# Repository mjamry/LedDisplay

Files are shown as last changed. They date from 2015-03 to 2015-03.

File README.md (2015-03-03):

# LedDisplay
This is a simple project which aim was to create LED display.<br>
Whole display is made using three 8x8 LED matrixes which are driven by ATMEL ATiny2313 microcontroller.<br><br>

Main aim was to put whole display into small case (Z76) which dimensions are 60x110mm.

For more detailed description, schematics and PCBs take a look at wiki pages.

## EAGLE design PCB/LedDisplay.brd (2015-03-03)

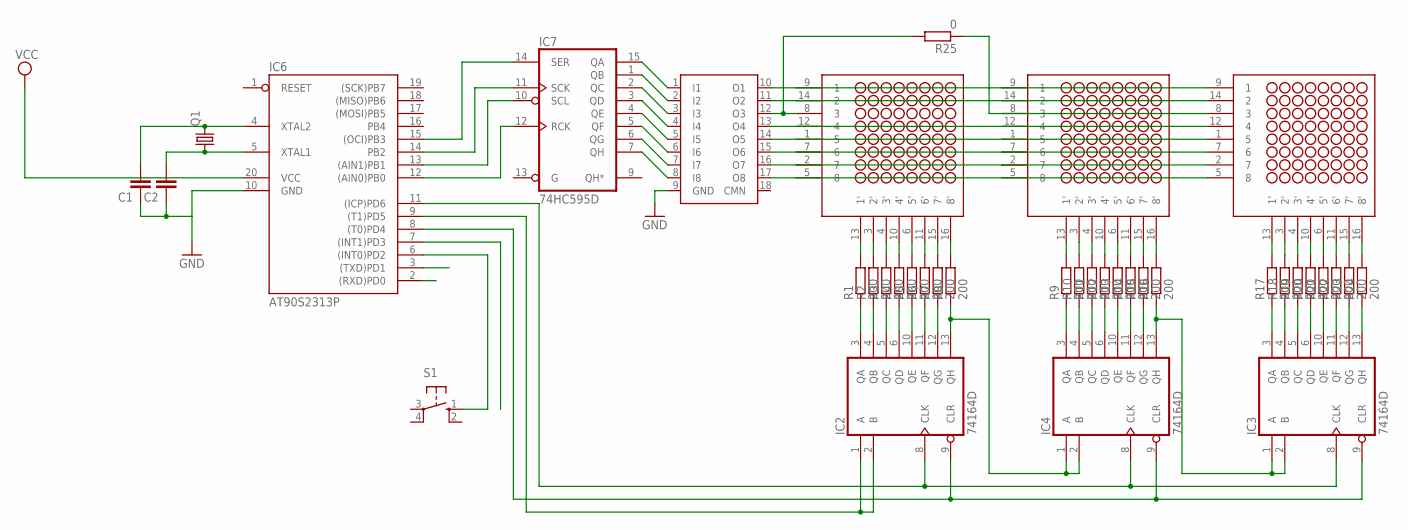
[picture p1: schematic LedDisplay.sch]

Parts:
C1, C2: C2,5-3; C2.5-3
IC2, IC3, IC4: 74164D; SO14
IC6: AT90S2313P; DIL20
IC7: 74HC595D; SO16
Q1: CRYSTALHC49U70; HC49U70
R1, R2, R3, R4, R5, R6, R7, R8, R9, R10, R11, R12, R13, R14, R15, R16, R17, R18, R19, R20, R21, R22, R23, R24: 200; M1206
R25: 0; M1206
S1: 10-XX; B3F-10XX
U$1, U$2, U$3: NFM-12881BG-11
U$4: ULN2803A; SO18W

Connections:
GND: C1.1, C2.1, IC2.7 (GND), IC3.7 (GND), IC4.7 (GND), IC6.10 (GND), IC7.8 (GND), U$4.9 (GND)
unnamed: IC7.7 (QH), U$4.8 (I8)
unnamed: IC7.6 (QG), U$4.7 (I7)
unnamed: IC7.5 (QF), U$4.6 (I6)
unnamed: IC7.4 (QE), U$4.5 (I5)
unnamed: IC7.3 (QD), U$4.4 (I4)
unnamed: IC7.2 (QC), U$4.3 (I3)
unnamed: IC7.1 (QB), U$4.2 (I2)
unnamed: IC7.15 (QA), U$4.1 (I1)
unnamed: R1.2, U$1.13 (1')
unnamed: R2.2, U$1.3 (2')
unnamed: R3.2, U$1.4 (3')
unnamed: R4.2, U$1.10 (4')
unnamed: R5.2, U$1.6 (5')
unnamed: R6.2, U$1.11 (6')
unnamed: R7.2, U$1.15 (7')
unnamed: R8.2, U$1.16 (8')
unnamed: IC2.3 (QA), R1.1
unnamed: IC2.4 (QB), R2.1
unnamed: IC2.5 (QC), R3.1
unnamed: IC2.6 (QD), R4.1
unnamed: IC2.10 (QE), R5.1
unnamed: IC2.11 (QF), R6.1
unnamed: IC2.12 (QG), R7.1
unnamed: IC2.13 (QH), IC4.1 (A), IC4.2 (B), R8.1
unnamed: R9.2, U$2.13 (1')
unnamed: R10.2, U$2.3 (2')
unnamed: R11.2, U$2.4 (3')
unnamed: R12.2, U$2.10 (4')
unnamed: R13.2, U$2.6 (5')
unnamed: R14.2, U$2.11 (6')
unnamed: R15.2, U$2.15 (7')
unnamed: R16.2, U$2.16 (8')
unnamed: IC4.3 (QA), R9.1
unnamed: IC4.4 (QB), R10.1
unnamed: IC4.5 (QC), R11.1
unnamed: IC4.6 (QD), R12.1
unnamed: IC4.10 (QE), R13.1
unnamed: IC4.11 (QF), R14.1
unnamed: IC4.12 (QG), R15.1
unnamed: IC3.1 (A), IC3.2 (B), IC4.13 (QH), R16.1
unnamed: R17.2, U$3.13 (1')
unnamed: R18.2, U$3.3 (2')
unnamed: R19.2, U$3.4 (3')
unnamed: R20.2, U$3.10 (4')
unnamed: R21.2, U$3.6 (5')
unnamed: R22.2, U$3.11 (6')
unnamed: R23.2, U$3.15 (7')
unnamed: R24.2, U$3.16 (8')
unnamed: IC3.3 (QA), R17.1
unnamed: IC3.4 (QB), R18.1
unnamed: IC3.5 (QC), R19.1
unnamed: IC3.6 (QD), R20.1
unnamed: IC3.10 (QE), R21.1
unnamed: IC3.11 (QF), R22.1
unnamed: IC3.12 (QG), R23.1
unnamed: IC3.13 (QH), R24.1
unnamed: C1.2, IC6.4 (XTAL2), Q1.2
unnamed: C2.2, IC6.5 (XTAL1), Q1.1
unnamed: IC2.9 (CLR), IC3.9 (CLR), IC4.9 (CLR), IC6.8 ((T0)PD4)
unnamed: IC2.1 (A), IC2.2 (B), IC6.9 ((T1)PD5)
unnamed: IC2.8 (CLK), IC3.8 (CLK), IC4.8 (CLK), IC6.11 ((ICP)PD6)
unnamed: IC6.6 ((INT0)PD2), S1.1 (S)
unnamed: U$1.9 (1), U$2.9 (1), U$3.9 (1), U$4.10 (O1)
unnamed: U$1.14 (2), U$2.14 (2), U$3.14 (2), U$4.11 (O2)
unnamed: R25.1, U$2.8 (3), U$3.8 (3)
unnamed: U$1.12 (4), U$2.12 (4), U$3.12 (4), U$4.13 (O4)
unnamed: U$1.1 (5), U$2.1 (5), U$3.1 (5), U$4.14 (O5)
unnamed: U$1.7 (6), U$2.7 (6), U$3.7 (6), U$4.15 (O6)
unnamed: U$1.2 (7), U$2.2 (7), U$3.2 (7), U$4.16 (O7)
unnamed: U$1.5 (8), U$2.5 (8), U$3.5 (8), U$4.17 (O8)
unnamed: IC6.12 ((AIN0)PB0), IC7.12 (RCK)
unnamed: IC6.13 ((AIN1)PB1), IC7.10 (SCL)
unnamed: IC6.14 (PB2), IC7.11 (SCK)
unnamed: IC6.15 ((OCI)PB3), IC7.14 (SER)
unnamed: R25.2, U$1.8 (3), U$4.12 (O3)
VCC: IC2.14 (VCC), IC3.14 (VCC), IC4.14 (VCC), IC6.20 (VCC), IC7.16 (VCC)

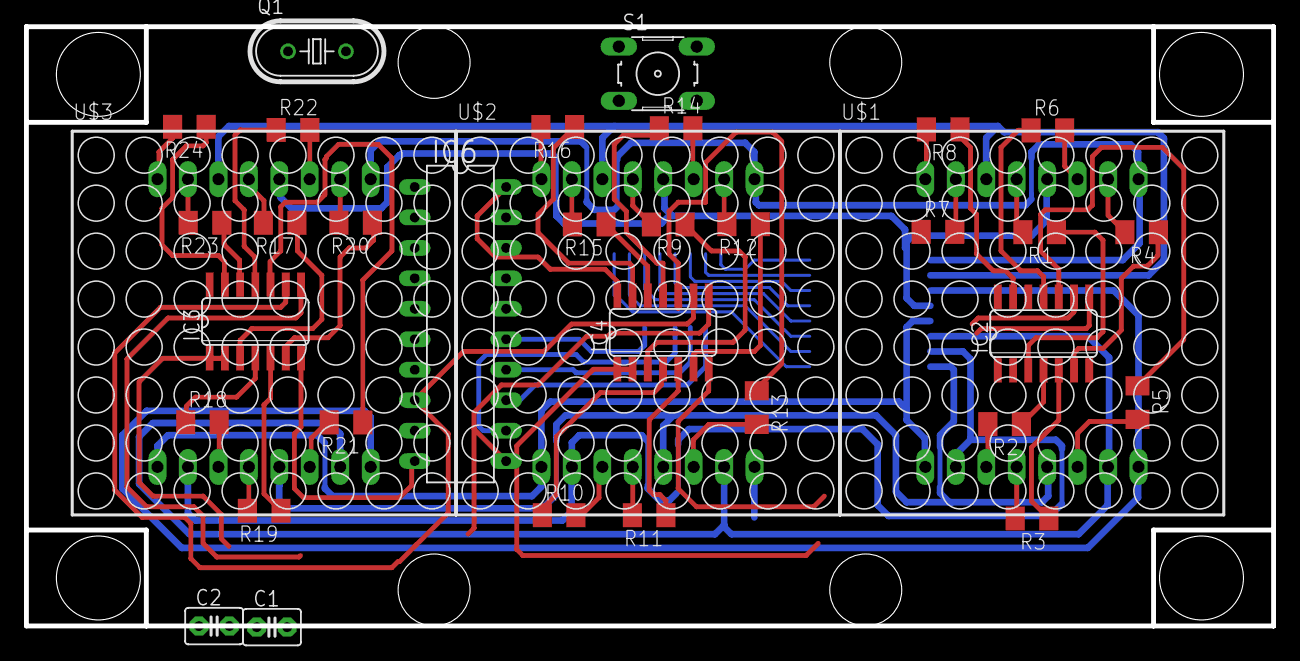
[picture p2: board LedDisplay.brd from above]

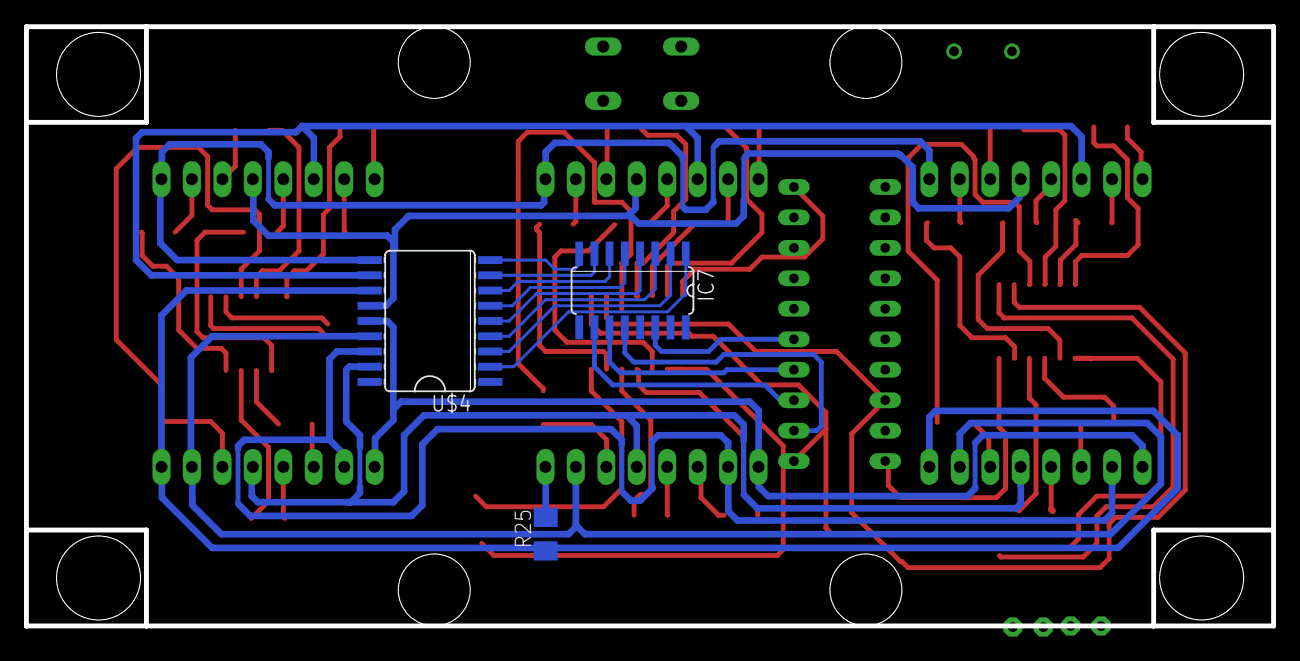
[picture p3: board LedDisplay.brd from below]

Board: 2 copper layers, 104.0 x 50.0 mm, 38 parts (3 on the bottom side), 77 nets.

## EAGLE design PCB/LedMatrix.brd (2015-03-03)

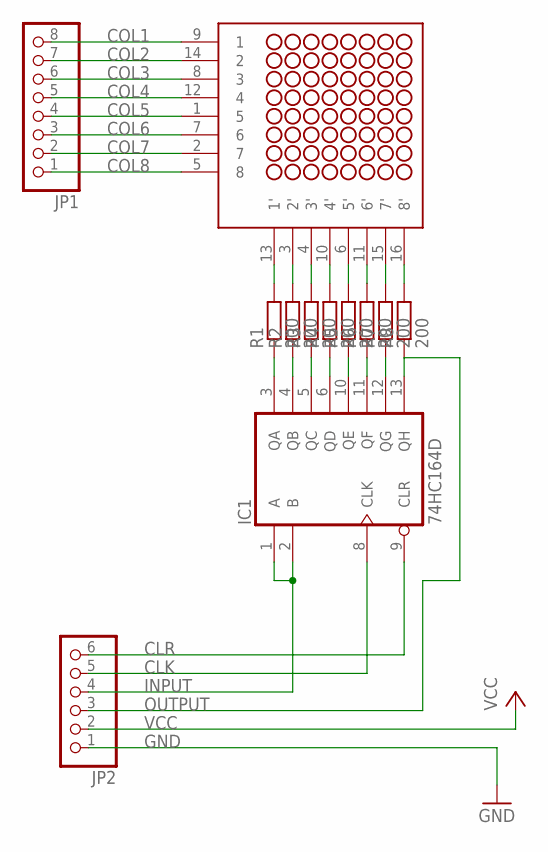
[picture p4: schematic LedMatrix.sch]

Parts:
IC1: 74HC164D; SO14
JP1: PINHD-1X8; 1X08
JP2: PINHD-1X6; 1X06
R1, R2, R3, R4, R5, R6, R7, R8: 200; R1206
U$1: NFM-12881BG-11

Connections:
CLK: IC1.8 (CLK), JP2.5
CLR: IC1.9 (CLR), JP2.6
COL1: JP1.8, U$1.9 (1)
COL2: JP1.7, U$1.14 (2)
COL3: JP1.6, U$1.8 (3)
COL4: JP1.5, U$1.12 (4)
COL5: JP1.4, U$1.1 (5)
COL6: JP1.3, U$1.7 (6)
COL7: JP1.2, U$1.2 (7)
COL8: JP1.1, U$1.5 (8)
GND: IC1.7 (GND), JP2.1
INPUT: IC1.1 (A), IC1.2 (B), JP2.4
unnamed: R1.2, U$1.13 (1')
unnamed: R2.2, U$1.3 (2')
unnamed: R3.2, U$1.4 (3')
unnamed: R4.2, U$1.10 (4')
unnamed: R5.2, U$1.6 (5')
unnamed: R6.2, U$1.11 (6')
unnamed: R7.2, U$1.15 (7')
unnamed: R8.2, U$1.16 (8')
unnamed: IC1.3 (QA), R1.1
unnamed: IC1.4 (QB), R2.1
unnamed: IC1.5 (QC), R3.1
unnamed: IC1.6 (QD), R4.1
unnamed: IC1.10 (QE), R5.1
unnamed: IC1.11 (QF), R6.1
unnamed: IC1.12 (QG), R7.1
OUTPUT: IC1.13 (QH), JP2.3, R8.1
VCC: IC1.14 (VCC), JP2.2

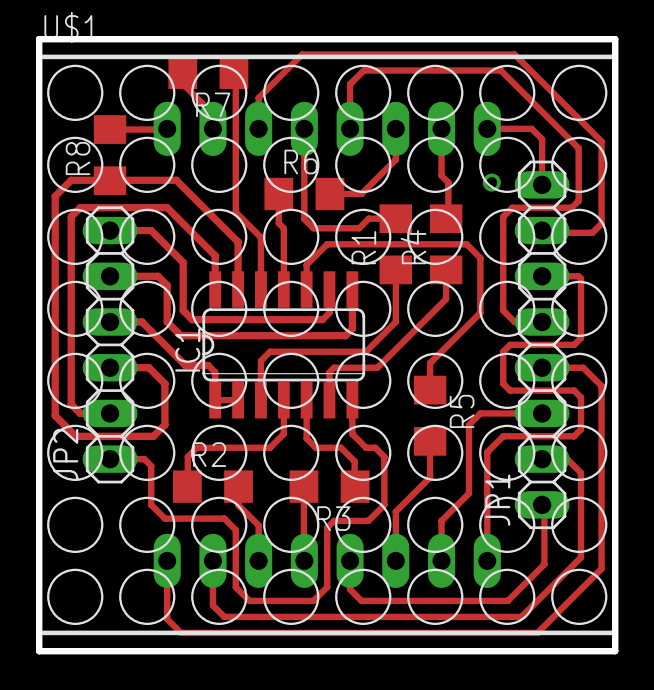
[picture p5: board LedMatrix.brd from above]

Board: 2 copper layers, 32.0 x 34.0 mm, 12 parts (0 on the bottom side), 29 nets.

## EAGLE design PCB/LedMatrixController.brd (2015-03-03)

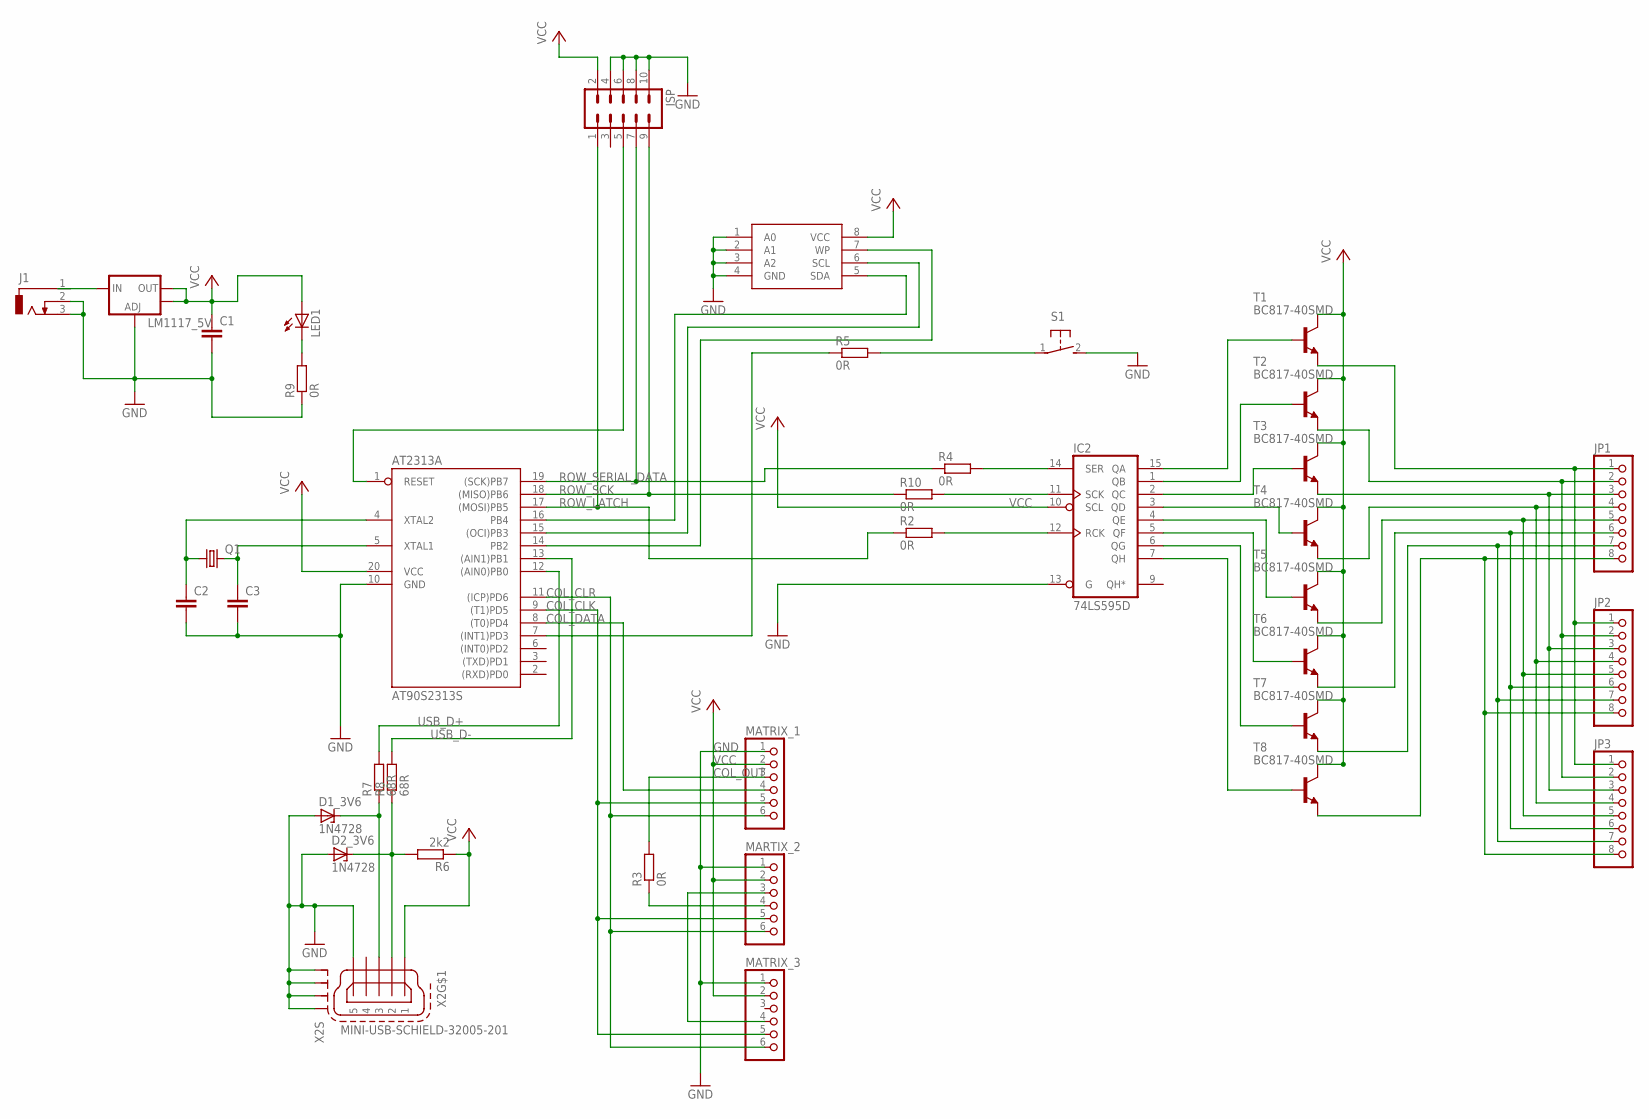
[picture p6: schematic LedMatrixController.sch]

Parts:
AT2313A: AT90S2313S; SO20L
C1: C-EU025-025X050; C025-025X050
C2, C3: C-EUC1206; C1206
D1_3V6, D2_3V6: 1N4728; DO41Z10
EEPROM: AT24C08; SO08
IC2: 74LS595D; SO16
ISP: ML10
J1: DCJ0303
JP1, JP2, JP3: PINHD-1X8; 1X08
LED1: LEDCHIPLED_1206; CHIPLED_1206
LM1117_5V: V_REG_LM1117SOT223; SOT223
MARTIX_2: PINHD-1X6; 1X06
MATRIX_1, MATRIX_3: PINHD-1X6; 1X06
Q1: CRYSTALHC49UP; HC49UP
R2, R3, R4, R5, R9, R10: 0R; R1206
R6: 2k2; R1206
R7, R8: 68R; R1206
S1: 31-XX; B3F-31XX
T1, T2, T3, T4, T5, T6, T7, T8: BC817-40SMD; SOT23-BEC
X2: MINI-USB-SCHIELD-32005-201; 32005-201

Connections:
+5V: IC2.16 (VCC)
COL_CLK: AT2313A.9 ((T1)PD5), MARTIX_2.5, MATRIX_1.5, MATRIX_3.5
COL_CLR: AT2313A.11 ((ICP)PD6), MARTIX_2.6, MATRIX_1.6, MATRIX_3.6
COL_DATA: AT2313A.8 ((T0)PD4), MATRIX_1.4
COL_OUT: MATRIX_1.3, R3.2
COL_OUT_2: MARTIX_2.4, R3.1
GND: AT2313A.10 (GND), C1.2, C2.2, C3.2, D1_3V6.A, D2_3V6.A, EEPROM.1 (A0), EEPROM.2 (A1), EEPROM.3 (A2), EEPROM.4 (GND), IC2.8 (GND), IC2.13 (G), ISP.4, ISP.6, ISP.8, ISP.10, J1.2, J1.3, LM1117_5V.1 (ADJ), MARTIX_2.1, MATRIX_1.1, MATRIX_3.1, R9.1, S1.2 (S), X2.5, X2.M1 (S1), X2.M2 (S2), X2.M3 (S3), X2.M4 (S4)
unnamed: AT2313A.4 (XTAL2), C2.1, Q1.1
unnamed: J1.1, LM1117_5V.3 (IN)
unnamed: AT2313A.5 (XTAL1), C3.1, Q1.2
unnamed: AT2313A.7 ((INT1)PD3), R5.1
unnamed: IC2.12 (RCK), R2.2
unnamed: AT2313A.16 (PB4), EEPROM.5 (SDA)
unnamed: IC2.14 (SER), R4.2
unnamed: MARTIX_2.3, MATRIX_3.4
unnamed: AT2313A.15 ((OCI)PB3), EEPROM.6 (SCL)
unnamed: IC2.11 (SCK), R10.2
unnamed: AT2313A.14 (PB2), EEPROM.7 (WP)
unnamed: AT2313A.1 (RESET), ISP.5
unnamed: R5.2, S1.1
unnamed: LED1.C, R9.2
R1: IC2.15 (QA), T1.B
R2: IC2.1 (QB), T2.B
R3: IC2.2 (QC), T3.B
R4: IC2.3 (QD), T4.B
R5: IC2.4 (QE), T5.B
R6: IC2.5 (QF), T6.B
R7: IC2.6 (QG), T7.B
R8: IC2.7 (QH), T8.B
ROW1: JP1.1, JP2.1, JP3.1, T1.E
ROW2: JP1.2, JP2.2, JP3.2, T2.E
ROW3: JP1.3, JP2.3, JP3.3, T3.E
ROW4: JP1.4, JP2.4, JP3.4, T4.E
ROW5: JP1.5, JP2.5, JP3.5, T5.E
ROW6: JP1.6, JP2.6, JP3.6, T6.E
ROW7: JP1.7, JP2.7, JP3.7, T7.E
ROW8: JP1.8, JP2.8, JP3.8, T8.E
ROW_LATCH: AT2313A.17 ((MOSI)PB5), ISP.1, R2.1
ROW_SCK: AT2313A.18 ((MISO)PB6), ISP.9, R10.1
ROW_SERIAL_DATA: AT2313A.19 ((SCK)PB7), ISP.7, R4.1
USB_D+: AT2313A.12 ((AIN0)PB0), R7.2
USB_D-: AT2313A.13 ((AIN1)PB1), R8.2
USB_DATA+: D1_3V6.C, R7.1, X2.3
USB_DATA-: D2_3V6.C, R6.2, R8.1, X2.2
VCC: AT2313A.20 (VCC), C1.1, EEPROM.8 (VCC), IC2.10 (SCL), ISP.2, LED1.A, LM1117_5V.2 (OUT), LM1117_5V.4 (OUT), MARTIX_2.2, MATRIX_1.2, MATRIX_3.2, R6.1, T1.C, T2.C, T3.C, T4.C, T5.C, T6.C, T7.C, T8.C, X2.1

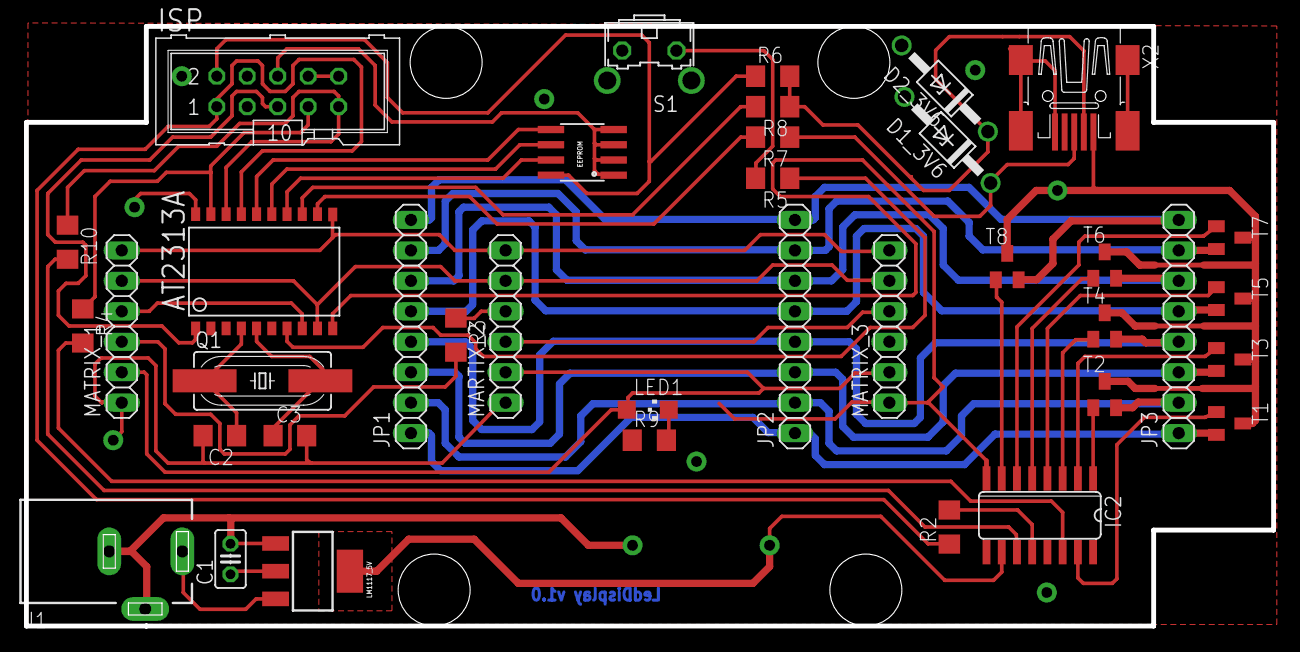
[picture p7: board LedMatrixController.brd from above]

Board: 2 copper layers, 104.0 x 50.0 mm, 38 parts (0 on the bottom side), 44 nets.

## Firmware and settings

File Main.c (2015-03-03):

#include <avr/io.h>
#include <util/delay.h>
#include <avr/interrupt.h>

#include "Const.h"
#include "MemoryData.h"

uint16_t memoryPointer = 0;
bool btnPressed = false;
uint8_t dataToDisplay[CHAR_LENGTH];

void initialiseTimer_1_B()
{
    //set CTC mode
    TCCR1B |= (1<<WGM12);
    //set prescaler to 64
    TCCR1B |= ((1<<CS11) | (1<<CS10));
    //set interrupt flag
    TIMSK |= (1<<OCIE1A);
    //set counter value
    OCR1A = 0x04F0;
}

void initialiseInt_1()
{
	//enable INT1
	GIMSK |= (1<<INT1);
	//The falling edge of INT1 generates an interrupt request
	MCUCR |= (1<<ISC11) | (1<<ISC10);
	//enable pull up resistor
	PORTD |= (1<<PD3);
}

void setUpIO()
{
    DDRB = 0xFF;
    DDRD = 0xF7;
}

//clocks column clock
void clockRegisterState()
{
	PORTD |= CLK;
	_delay_us(DELAY_COL);
	PORTD &= ~(CLK);
	_delay_us(DELAY_COL);
}

//put data in the middle, and fill rest with empty space (LEDs turned off)
void resizeDataArray(uint8_t input[], uint8_t inputLength, uint8_t output[])
{
	uint8_t i=0;
	uint8_t fillData = 0x00;
	if(inputLength < CHAR_LENGTH)
	{
		uint8_t rightSize = (CHAR_LENGTH - inputLength)/2;
		//if array length is odd left side will have one element more than right
		uint8_t leftSize = rightSize + (CHAR_LENGTH - inputLength)%2;
		//fill right side
		for(i=0;i<rightSize;i++)
		{
			output[i] = fillData;
		}
		//add data in the middle
		for(i=rightSize;i<rightSize + inputLength;i++)
		{
			output[i] = input[i-rightSize];
		}
		//fill left side
		for(i=rightSize+inputLength;i<rightSize+inputLength+leftSize;i++)
		{
			output[i] = fillData;
		}
	}
}

//reads data from the memory using pointer.
//pointer is incremented after reading data.
void readDataFromMemory(uint8_t memory[], uint8_t output[])
{
	uint8_t i=0;
	uint8_t memoryData[CHAR_LENGTH];
	while(memory[memoryPointer] != '\0')
	{
		memoryData[i] = memory[memoryPointer];
		i++;
		memoryPointer++;
	}

	memoryPointer++;
	resizeDataArray(memoryData, i, output);
}

//timer interrupt handler
ISR(TIMER1_COMPA_vect)
{
	//at the moment does nothing
}

//external interrupt handler
ISR(INT1_vect)
{
	btnPressed = true;
}

void putOutRowData(uint8_t data)
{
	uint8_t i=0;
	uint8_t temp = 0;

	for(i=0;i<8;i++)
	{
		temp = data & 0x80;
		if(temp)
		{
			PORTB |= (1<<PB7);
		}
		else
		{
			PORTB &= ~(1<<PB7);
		}

		data = data << 1;

		PORTB &= ~(ROW_SERIAL_CLK);
		_delay_us(DELAY_ROW);
		PORTB |= (ROW_SERIAL_CLK);
	}

	PORTB &= ~(ROW_LATCH);
	_delay_us(DELAY_ROW);
	PORTB |= ROW_LATCH;
}

int main(void)
{
    uint8_t j=0;

    setUpIO();
    initialiseTimer_1_B();
    initialiseInt_1();
    //set global interrupt flag
    sei();

    while(1)
    {
		PORTD |= RST;
		//puts 0 to the output which will selects current column
		PORTD &= ~(OUT);
		//handle button pressed
		if(btnPressed)
		{
			memoryPointer++;
			if(memoryPointer == NUMBER_OF_GRAPHICS)
			{
				memoryPointer = 0;
			}

			btnPressed = false;
		}
		for(j=0;j<MATRIX_LENGTH;j++)
		{
			putOutRowData(GRAPHICS[memoryPointer*MATRIX_LENGTH+j]);
			clockRegisterState();
			PORTD |= OUT;
		}
    }

    return 0;
}

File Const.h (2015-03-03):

#ifndef CONS_H_
#define CONS_H_

#define DELAY_ROW 80
#define DELAY_COL 120
#define CHARS_NUMBER 8
#define CHAR_LENGTH 8
#define MATRIX_LENGTH 24
#define NUMBER_OF_GRAPHICS 7

uint8_t GRAPHICS[MATRIX_LENGTH*NUMBER_OF_GRAPHICS] = {
									//[1] space invaders 1
									0x80, 0x5C, 0xB6, 0x5F, 0x5F, 0xB6, 0x5C, 0x80,
									0x01, 0x01, 0x01, 0x01, 0x01, 0x01, 0x01, 0x01,
									0x01, 0x01, 0x01, 0x01, 0x01, 0x01, 0x01, 0x01,
									//[2] space invaders 2
									0x02, 0x02 ,0x02 ,0x02 ,0x02 ,0x02 ,0x02 ,0x02,
									0x98, 0x5C, 0xB6, 0x5F, 0x5F, 0xB6, 0x5C, 0x98,
									0x02, 0x02 ,0x02 ,0x02 ,0x02 ,0x02 ,0x02 ,0x02,
									//[3] space invaders 3
									0x04, 0x04, 0x04, 0x04, 0x04, 0x04, 0x04, 0x04,
									0x04, 0x04, 0x04, 0x04, 0x04, 0x04, 0x04, 0x04,
									0x38, 0x1D, 0x76, 0x9C, 0x9C, 0x76, 0x1D, 0x38,
									//[4] three smiles
									0x3C, 0x42, 0x95, 0xA1, 0xA1, 0x95, 0x42, 0x3C,
									0x3C, 0x42, 0x95, 0xA1, 0xA1, 0x95, 0x42, 0x3C,
									0x3C, 0x42, 0x95, 0xA1, 0xA1, 0x95, 0x42, 0x3C,
									//[5] space invaders 4
									0x78, 0x3D, 0x76, 0xBC, 0xBC, 0x76, 0x3D, 0x78,
									0x08, 0x08, 0x08, 0x08, 0x08, 0x08, 0x08, 0x08,
									0x08, 0x08, 0x08, 0x08, 0x08, 0x08, 0x08, 0x08,
									//[6] hearts
									0x1C, 0x3E, 0x7E, 0xFC, 0xFC, 0x7E, 0x3E, 0x1C,
									0x1C, 0x3E, 0x7E, 0xFC, 0xFC, 0x7E, 0x3E, 0x1C,
									0x1C, 0x3E, 0x7E, 0xFC, 0xFC, 0x7E, 0x3E, 0x1C,
									//[7] be happy
									0x00, 0xFF, 0x88, 0x88, 0x88, 0x70, 0x00, 0x70,
									0xA8, 0xA8, 0xA8, 0x30, 0x00, 0x3C, 0x42, 0x91,
									0xAD, 0xAD, 0xA1, 0xAD, 0xAD, 0x91, 0x42, 0x3C,
									};

#define COL_PORT PORTD

#define CLK 0x20
#define OUT 0x10
#define RST 0x40

#define ROW_PORT PORTB

#define ROW_DATA 0x80
#define _ROW_OUTPUT_ENABLE 0x02
#define ROW_LATCH 0x20
#define ROW_SERIAL_CLK 0x40
#define _ROW_CLR 0x10

typedef int bool;
#define true 1
#define false 0

#endif /* CONS_H_ */

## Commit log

2015-01-27 Minor code clean up changes. Removed unwanted reset from the end of the loop.
    [Main.c]
2015-01-28 Added new character to display. Reset has been moved.
    [Main.c]
2015-01-29 Added timer1 channel A CTC mode interrupt handler. Also some additional code to test interupt.
2015-01-29 Added simple animation as a POF of using interrupts to drive animations.
2015-01-29 Minor changes in timer settings.
2015-02-01 Added PCB project with empty schematic file.
    [LedDisplay.sch]
2015-02-01 Added basic elements to the schematics. Added dimensions and holes to the pcb.
    [LedDisplay.brd, LedDisplay.sch]
2015-02-02 Updated pcb dimensions. Now is fits perfectly to the casing. Also some of the elements were changed to DIP packages.
    [LedDisplay.brd, LedDisplay.sch]
2015-02-02 Another part of improvements in pcb layout, especially on the top layer.
    [LedDisplay.brd, LedDisplay.sch]
2015-02-04 New versions of pcb. This time smaller one, just as a led controller.
    [LedMatrix.brd, LedMatrix.sch]
2015-02-04 Added new pcb which main aim is to drive led matrixes. It will contains cpu, and power source.
    [LedMatrixController.brd, LedMatrixController.sch]
2015-02-04 Added connections between main elements. Created dimensions on the pbc layout.
    [LedMatrixController.brd, LedMatrixController.sch]
2015-02-04 Updated led matrix board.
    [LedMatrix.brd]
2015-02-04 Minor corrections to the led matrix board.
    [LedMatrix.brd]
2015-02-05 Minor measure corrections on the matrix board.
    [LedMatrix.brd]
2015-02-05 Corrected positions of pinheads on the matrix controller board.
    [LedMatrixController.brd, LedMatrixController.sch]
2015-02-09 Another part of improvements in pcb layouts. Especially in pinhead area, to match both pcbs.
    [LedMatrix.brd, LedMatrix.sch, LedMatrixController.brd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]
2015-02-09 Improvments in the top layer of matrix controller pcb. Added eeprom, connected power source and almost all IC.
    [LedMatrixController.brd, LedMatrixController.sch]
2015-02-11 Added usb connector, and power led.
    [LedMatrixController.brd, LedMatrixController.sch]
2015-02-11 Added descriptions to the lines on the ledMatrix board.
    [LedMatrix.brd, LedMatrix.sch]
2015-02-14 Finished first version of the led matrix controller pcb
    [LedMatrixController.brd, LedMatrixController.sch]
2015-02-19 Modified pinouts according to new wersion of the PCB. Modified delays to be more appropriate for 3 led martixes.
2015-02-19 Basic int1 handling by adding method to call during interrupt routine.
2015-02-20 Added fancy graphics to display on the led matrix
2015-03-03 Added button handling using external interrupt.
2015-03-03 ULN2803 has been replaced with NPN transistors
    [LedMatrixController.brd, LedMatrixController.sch]

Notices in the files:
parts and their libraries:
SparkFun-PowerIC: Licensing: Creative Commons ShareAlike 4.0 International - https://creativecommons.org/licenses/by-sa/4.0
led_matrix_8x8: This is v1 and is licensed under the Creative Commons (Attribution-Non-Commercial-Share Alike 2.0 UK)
